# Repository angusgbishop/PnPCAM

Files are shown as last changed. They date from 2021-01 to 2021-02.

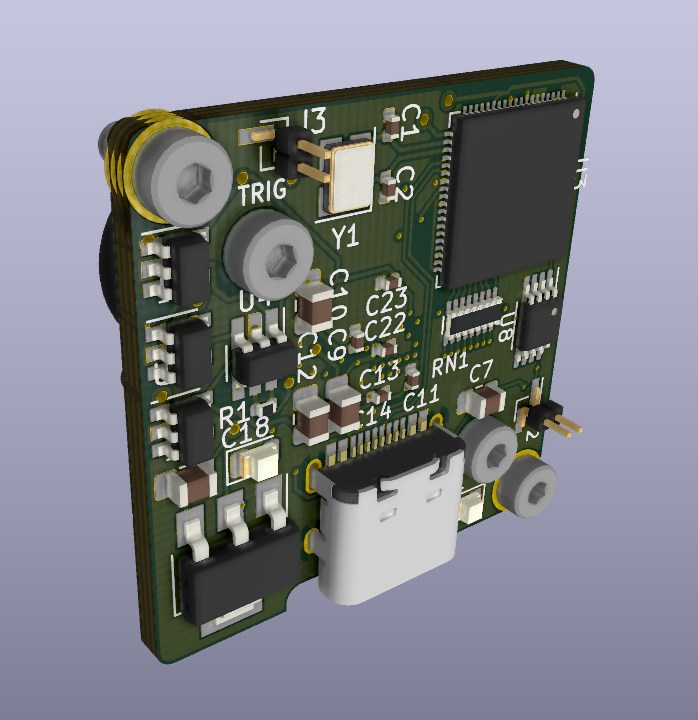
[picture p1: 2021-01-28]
OpenPnPVis Back.png

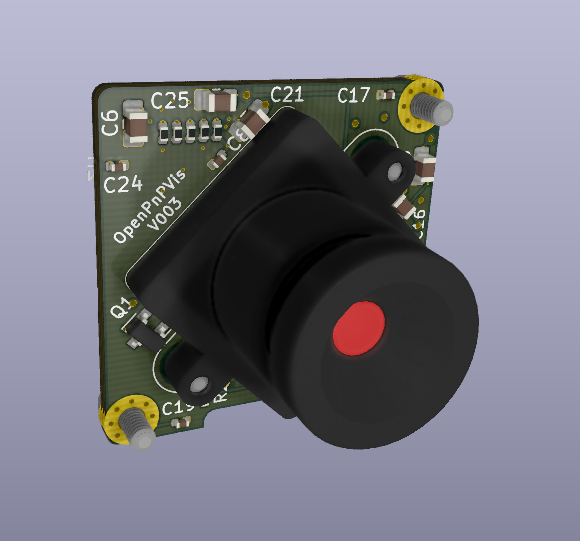
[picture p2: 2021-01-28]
OpenPnPVis Front.png

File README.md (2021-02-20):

# PnPCAM
 
PnPCAM is an [Open Hardware](https://www.oshwa.org/definition/) project dedicated to bringing high-quality machine vision to the various open source pick-and-place projects.

This project is very much **in development**, clone at your own risk!

The current versions of the board are based off the OnSemi AR0144 image sensor, as it is avaliable through mainline distributers at a reasonable cost for low quantities. 

* Up-to 1200x800 pixel resolution at 30fps (Currently limited by USB Bridge Chip)
* Global shutter
* Standard Webcam USB out
* <s>Onboard LED with exposure-triggered flash</s> (Requirement Dropped)
* LED Expansion Header for third-party use of the flash signal.
* Triggered shutter mode.
* Onboard lens distortion correction.

# Interested?
[View the Wiki here](https://github.com/angusgbishop/PnPCAM/wiki)

Find me on the [OpenPnP Discord](https://discord.gg/EmsrFVx)

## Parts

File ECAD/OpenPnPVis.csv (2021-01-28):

Reference | Quantity | Value | Footprint | Datasheet | MPN | SKU
C1 C2 | 2 | 16pF | Capacitor_SMD:C_0402_1005Metric | ~ | CC0402JRNPO9BN160
C10 C12 C14 C21 C25 C6 C3 C4 C15 C16 C18 C5 C7 | 13 | 10uF | Capacitor_SMD:C_0805_2012Metric_Pad1.15x1.40mm_HandSolder | ~ | CL21A106KOQNNNE
C9 C11 C13 C22 C23 C24 C8 C19 C17 | 9 | 100nF | Capacitor_SMD:C_0402_1005Metric | ~ | CC0402KRX7R7BB104
D1 D2 | 2 | LED | LED_SMD:LED_0805_2012Metric | ~ | ORH-B35A
H2 H1 | 2 | M3 | MountingHole:MountingHole_2.2mm_M2_Pad_Via | ~ | N/A
J2 J3 | 2 | Conn_01x02 | Connector_PinHeader_1.00mm:PinHeader_1x02_P1.00mm_Vertical_SMD_Pin1Left | ~
J4 | 1 | USB_C_Receptacle | Type-C:HRO-TYPE-C-31-M-12-Assembly | https://www.usb.org/sites/default/files/documents/usb_type-c.zip | TYPE-C-31-M-12
LENSMOUNT1 | 1 | CMT168-1122F | OpenPnPVis:CMT168-1122F | http://www.optics-online.com/Detail.asp?PN=CMT168-1122F | N/A
Q1 | 1 | SMD-MOSFET-P-CH-8V-4.1A-CJ2305_SOT-23_ | Package_TO_SOT_SMD:SOT-23 |  | CJ2305 | 305030014
R10 R11 R9 R12 R13 R8 | 6 | 1.6K | Resistor_SMD:R_0402_1005Metric | ~ | RC0402FR-071K5L
R19 R20 R4 R3 | 4 | 0R | Resistor_SMD:R_0402_1005Metric | ~ | RC0402FR-070RL
R2 | 1 | 85 | Resistor_SMD:R_0402_1005Metric | ~ | RC0402FR-0785RL
R5 R14 | 2 | 5.1K | Resistor_SMD:R_0402_1005Metric | ~ | RC0402FR-075K1L
R6 | 1 | 4.7K | Resistor_SMD:R_0402_1005Metric | ~ | RC0402FR-074K7L
R7 R1 | 2 | 10K | Resistor_SMD:R_0402_1005Metric | ~ | RC0402JR-0710KL
RN1 | 1 | 33 | Resistor_SMD:R_Array_Convex_8x0602 | ~ | EXB2HV330JV
U1 | 1 | AMS1117-3.3 | Package_TO_SOT_SMD:SOT-223-3_TabPin2 | http://www.advanced-monolithic.com/pdf/ds1117.pdf | AMS1117-3.3
U10 | 1 | AP2127K-2.5 | Package_TO_SOT_SMD:SOT-23-5 | https://www.diodes.com/assets/Datasheets/AP2127.pdf | AP2127K-2.5
U2 | 1 | AR0144 | OpenPnPVis:BGA-72_9x8_5.565x5.545mm |  | AR0144
U3 | 1 | FT602Q | Package_DFN_QFN:QFN-76-1EP_9x9mm_P0.4mm_EP3.8x3.8mm |  | FT602Q-B-T
U4 | 1 | ATtiny10-TS | Package_TO_SOT_SMD:SOT-23-6_Handsoldering | http://ww1.microchip.com/downloads/en/DeviceDoc/Atmel-8127-AVR-8-bit-Microcontroller-ATtiny4-ATtiny5-ATtiny9-ATtiny10_Datasheet.pdf | ATtiny10-TS
U6 | 1 | TPD2EUSB30 | Package_TO_SOT_SMD:Texas_DRT-3 | http://www.ti.com/lit/ds/symlink/tpd2eusb30a.pdf | TPD2EUSB30
U7 | 1 | AP2127K-2.8 | Package_TO_SOT_SMD:SOT-23-5 | https://www.diodes.com/assets/Datasheets/AP2127.pdf | AP2127K-2.8
U8 | 1 | 74LVC2G74 | Package_SO:MSOP-8_3x3mm_P0.65mm | http://www.ti.com/lit/sg/scyt129e/scyt129e.pdf | 74LVC2G74
U9 | 1 | AP2127K-1.2 | Package_TO_SOT_SMD:SOT-23-5 | https://www.diodes.com/assets/Datasheets/AP2127.pdf | AP2127K-1.2
Y1 | 1 | X3S030000BA1H-U | Crystal:Crystal_SMD_3225-4Pin_3.2x2.5mm | https://datasheet.lcsc.com/szlcsc/1912111437_HELE-Harmony-Elec-X3S030000BA1H-U_C254267.pdf | X3S030000BA1H-U

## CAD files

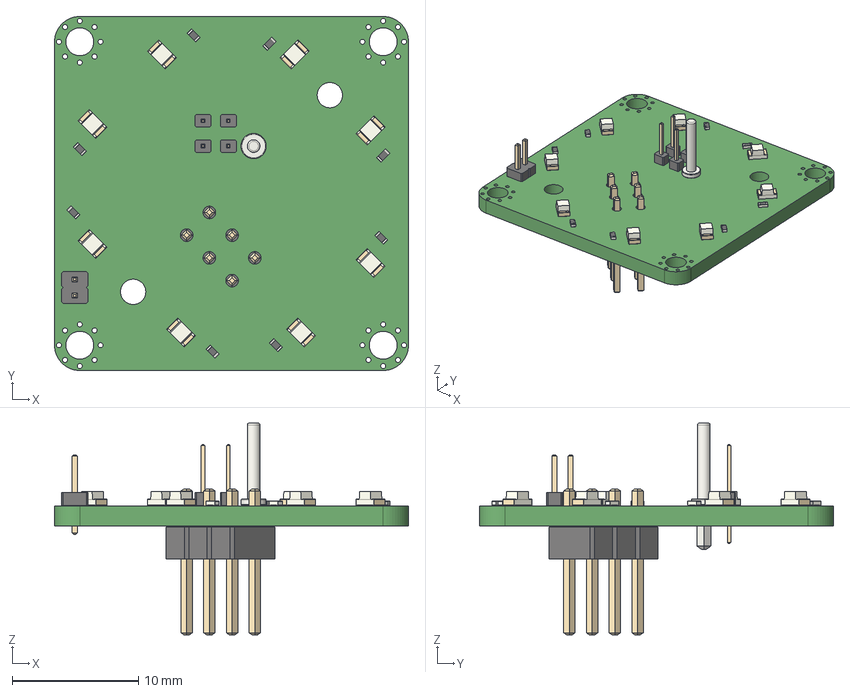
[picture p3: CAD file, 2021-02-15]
ECAD/Illumination Board/Illum/Illum.step
28.0 x 28.0 x 16.7 mm

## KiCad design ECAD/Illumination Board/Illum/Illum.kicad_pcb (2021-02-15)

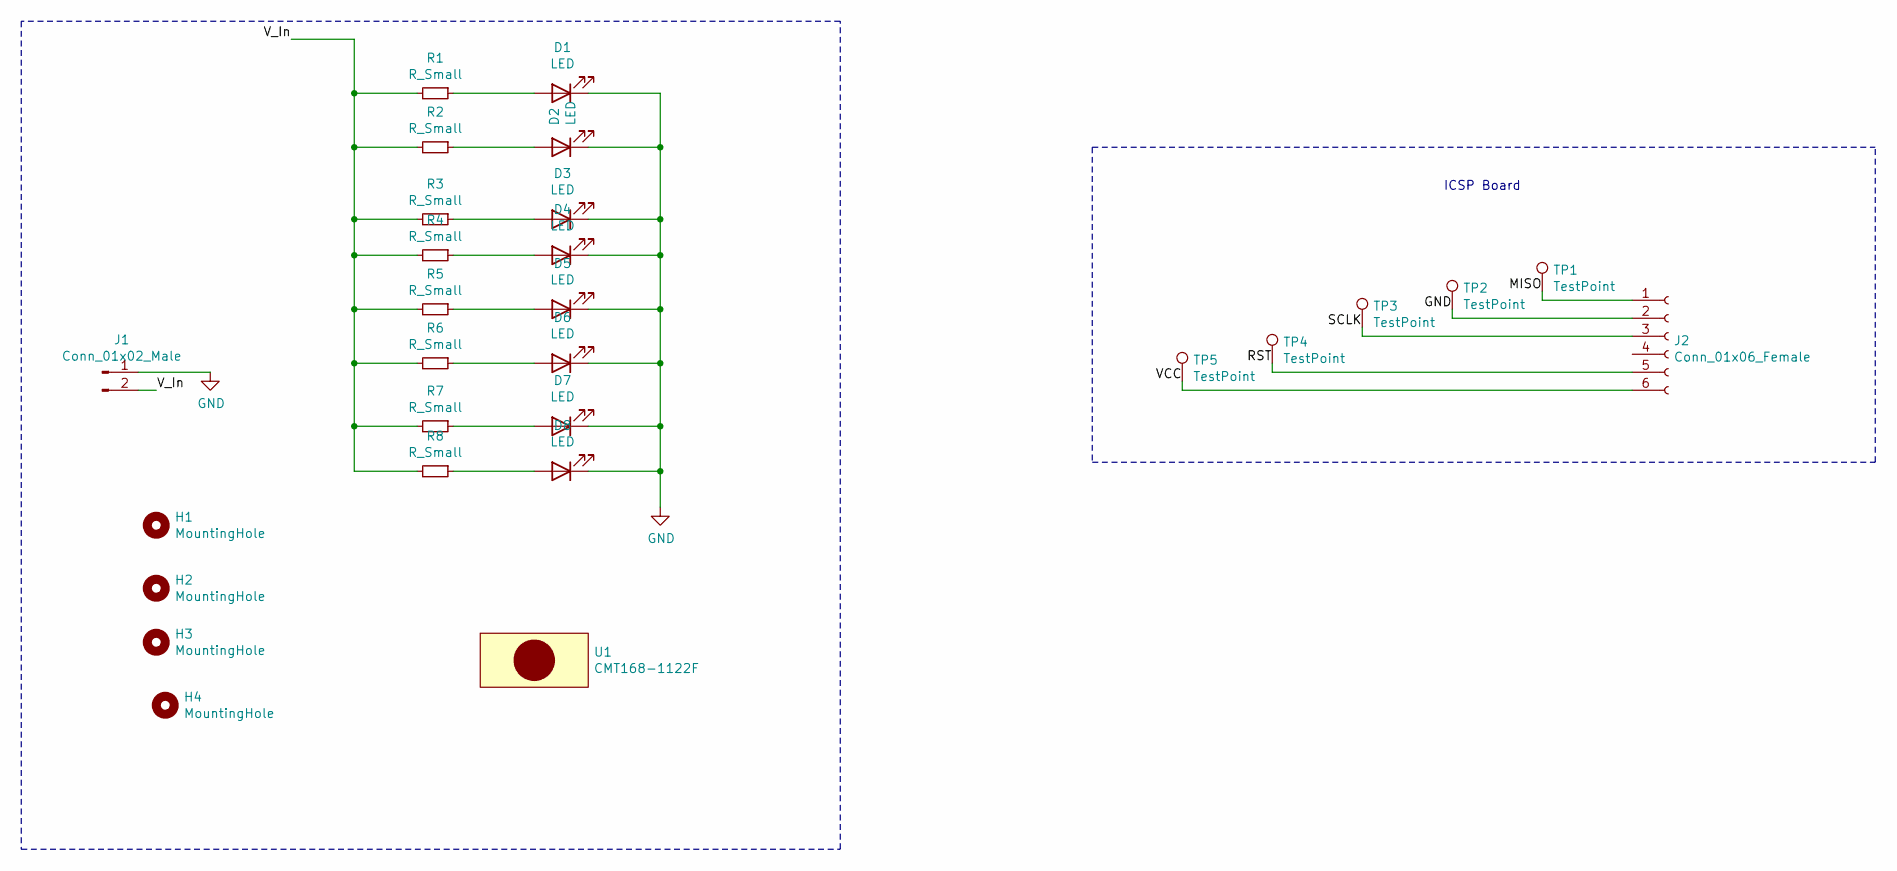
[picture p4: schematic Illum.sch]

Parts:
D1, D2, D3, D4, D5, D6, D7, D8: LED; LED_0805_2012Metric
H1, H2, H3, H4: MountingHole; MountingHole_2.2mm_M2_Pad_Via
J1: Conn_01x02_Male; PinHeader_1x02_P1.27mm_Vertical
J2: Conn_01x06_Female; PinHeader_2x03_P2.54mm_Vertical
R1, R2, R3, R4, R5, R6, R7, R8: R_Small; R_0402_1005Metric
TP1, TP2, TP3, TP4, TP5: TestPoint; PinHeader_1x01_P1.00mm_Vertical
U1: CMT168-1122F

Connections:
/MISO: J2.1, TP1.1
/RST: J2.5, TP4.1
/SCLK: J2.3, TP3.1
/VCC: J2.6, TP5.1
/V_In: J1.2, R1.2, R2.2, R3.2, R4.2, R5.2, R6.2, R7.2, R8.2
GND: D1.1 (K), D2.1 (K), D3.1 (K), D4.1 (K), D5.1 (K), D6.1 (K), D7.1 (K), D8.1 (K), J1.1, J2.2, TP2.1
unnamed: D1.2 (A), R1.1
unnamed: D2.2 (A), R2.1
unnamed: D3.2 (A), R3.1
unnamed: D4.2 (A), R4.1
unnamed: D5.2 (A), R5.1
unnamed: D6.2 (A), R6.1
unnamed: D7.2 (A), R7.1
unnamed: D8.2 (A), R8.1

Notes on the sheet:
ICSP Board

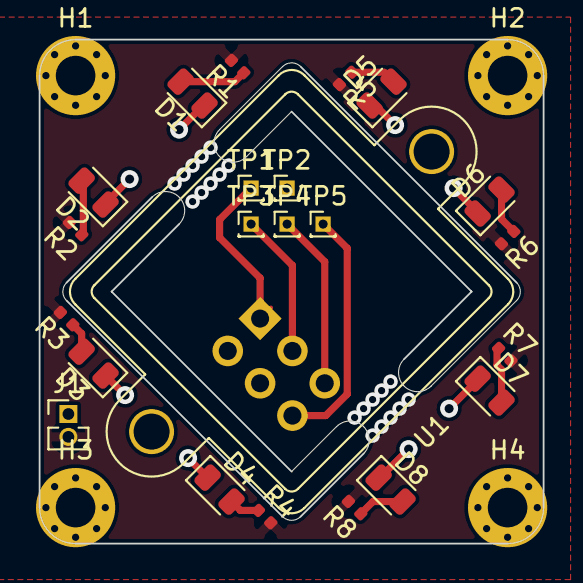
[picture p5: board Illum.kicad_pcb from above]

Board: 2 copper layers, 28.0 x 28.0 mm, 28 parts (1 on the bottom side), 14 nets.

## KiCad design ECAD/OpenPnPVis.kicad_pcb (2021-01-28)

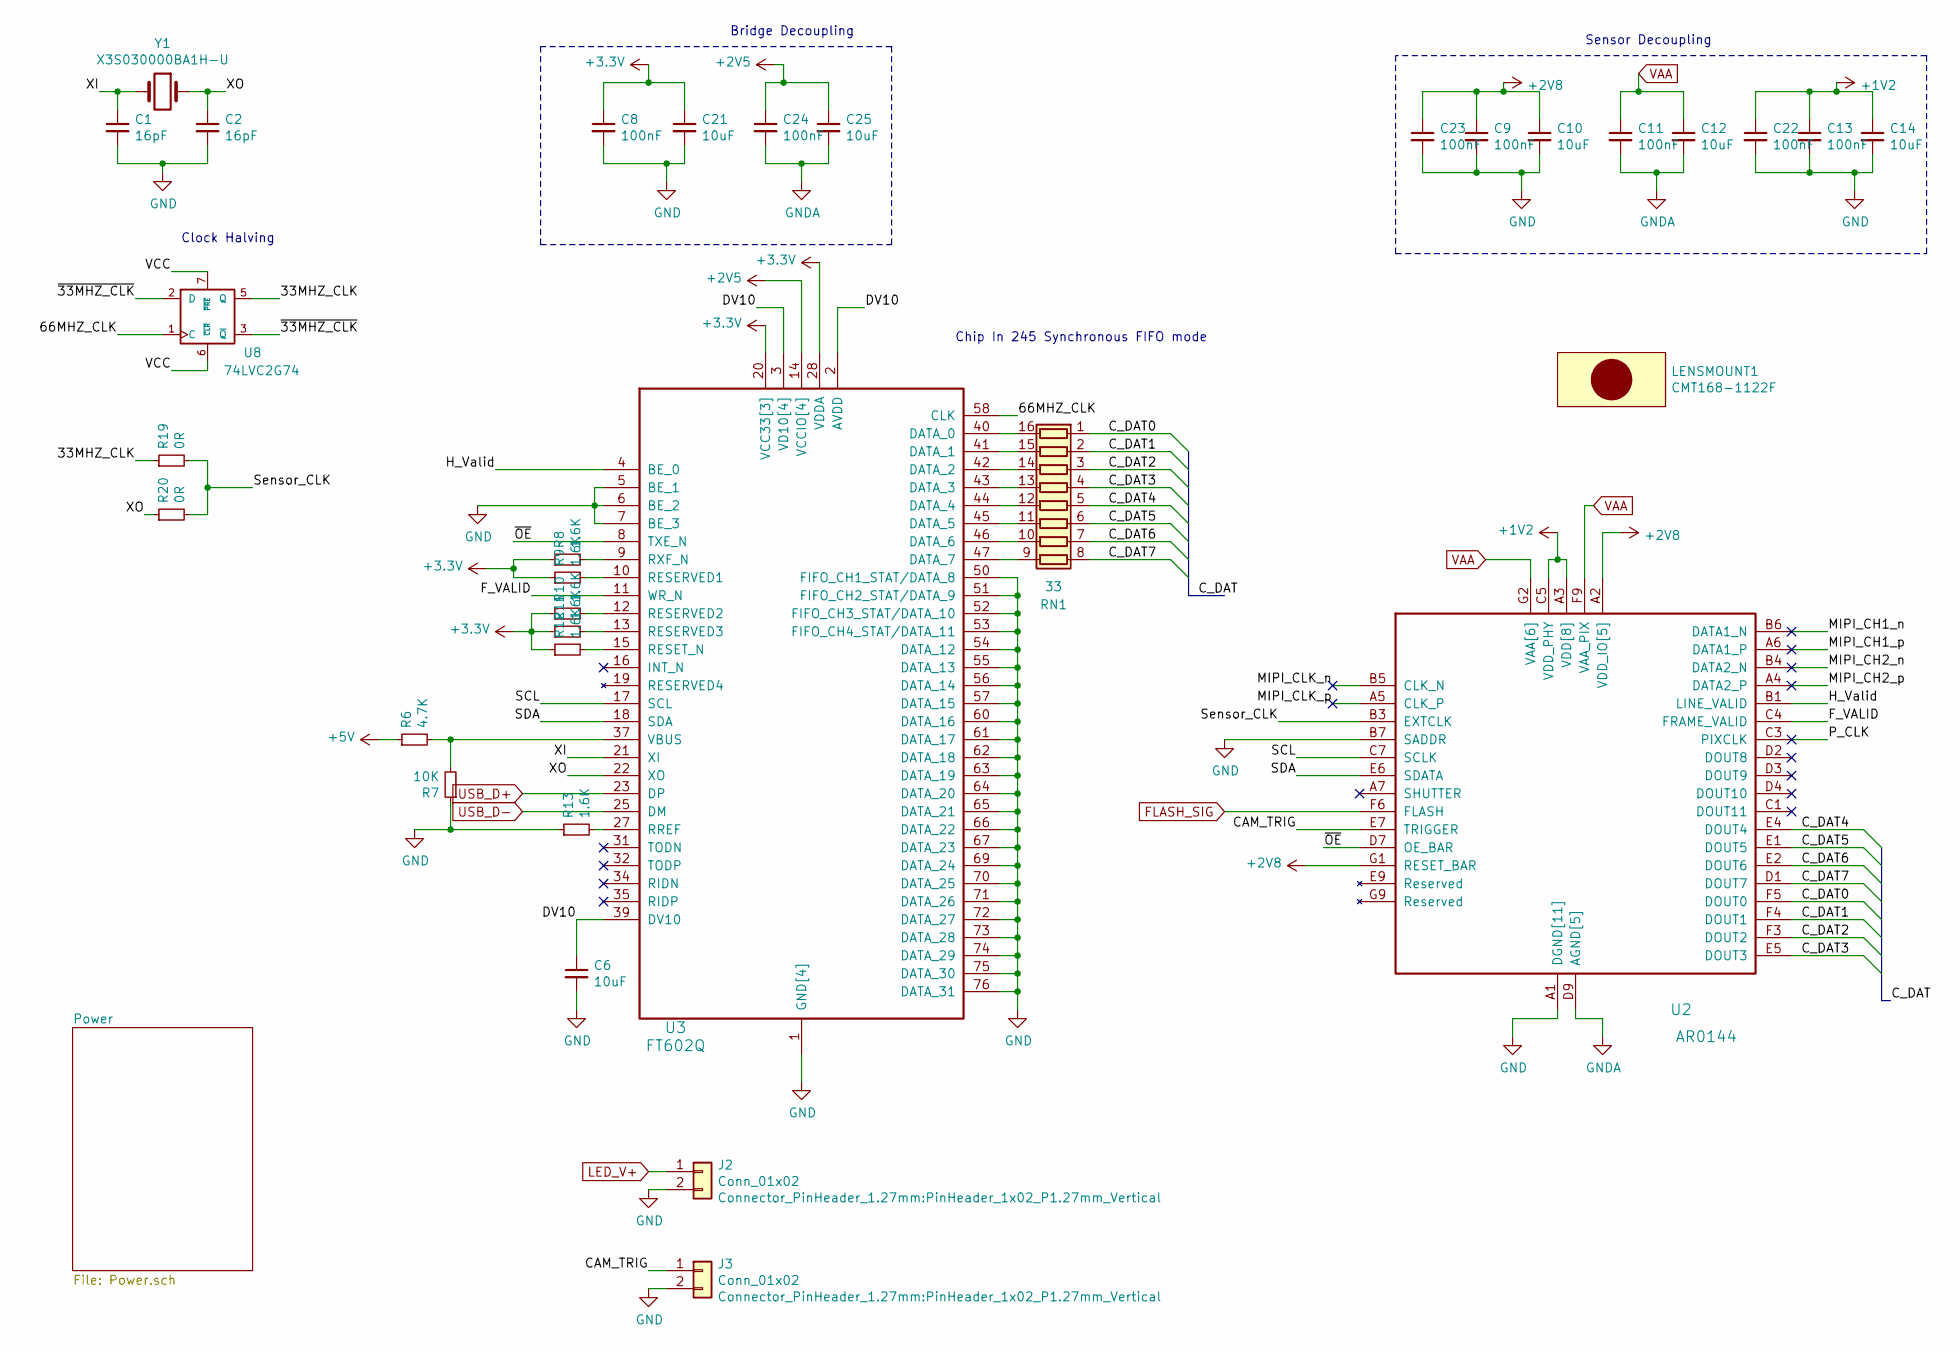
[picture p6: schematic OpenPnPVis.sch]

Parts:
C1, C2: 16pF; C_0402_1005Metric; MPN CC0402JRNPO9BN160
C6, C10, C12, C14, C21, C25: 10uF; C_0805_2012Metric_Pad1.15x1.40mm_HandSolder; MPN CL21A106KOQNNNE
C8, C9, C11, C13, C22, C23, C24: 100nF; C_0402_1005Metric; MPN CC0402KRX7R7BB104
J2, J3: Conn_01x02; PinHeader_1x02_P1.27mm_Vertical
LENSMOUNT1: CMT168-1122F; MPN N/A
R6: 4.7K; R_0402_1005Metric; MPN RC0402FR-074K7L
R7: 10K; R_0402_1005Metric; MPN RC0402JR-0710KL
R8, R9, R10, R11, R12, R13: 1.6K; R_0402_1005Metric; MPN RC0402FR-071K5L
R19, R20: 0R; R_0402_1005Metric; MPN RC0402FR-070RL
RN1: 33; R_Array_Convex_8x0602; MPN EXB2HV330JV
U2:  AR0144; BGA-72_9x8_5.565x5.545mm; MPN AR0144
U3: FT602Q; QFN-76-1EP_9x9mm_P0.4mm_EP3.8x3.8mm; MPN FT602Q-B-T
U8: 74LVC2G74; VSSOP-8_2.4x2.1mm_P0.5mm; MPN 74LVC2G74
Y1: X3S030000BA1H-U; Crystal_SMD_3225-4Pin_3.2x2.5mm; MPN X3S030000BA1H-U

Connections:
+1V2: C13.1, C14.1, C22.1, U2.A3 (VDD[8]), U2.B2 (VDD[8]), U2.C5 (VDD_PHY), U2.C6 (VDD[8]), U2.D8 (VDD[8]), U2.F2 (VDD[8]), U2.G4 (VDD[8]), U2.G5 (VDD[8]), U2.G6 (VDD[8]); also elsewhere on the board
+2V8: C9.1, C10.1, C23.1, U2.A2 (VDD_IO[5]), U2.B8 (VDD_IO[5]), U2.C2 (VDD_IO[5]), U2.C8 (VDD_IO[5]), U2.E3 (VDD_IO[5]), U2.G1 (RESET_BAR), U8.6 (~CLR), U8.7 (~PRE), U8.8 (VCC); also elsewhere on the board
+3V3: C8.1, C21.1, R8.1, R9.1, R10.1, R11.1, R12.1, U3.20 (VCC33[3]), U3.24 (VCC33[3]), U3.28 (VDDA), U3.38 (VCC33[3]); also elsewhere on the board
+5V: R6.1; also elsewhere on the board
/33MHZ_CLK: R19.1, U8.5 (Q)
/66MHZ_CLK: U3.58 (CLK), U8.1 (C)
/CAM_TRIG: J3.1, U2.E7 (TRIGGER)
/C_DAT0: RN1.1 (R1.1), U2.F5 (DOUT0)
/C_DAT1: RN1.2 (R2.1), U2.F4 (DOUT1)
/C_DAT2: RN1.3 (R3.1), U2.F3 (DOUT2)
/C_DAT3: RN1.4 (R4.1), U2.E5 (DOUT3)
/C_DAT4: RN1.5 (R5.1), U2.E4 (DOUT4)
/C_DAT5: RN1.6 (R6.1), U2.E1 (DOUT5)
/C_DAT6: RN1.7 (R7.1), U2.E2 (DOUT6)
/C_DAT7: RN1.8 (R8.1), U2.D1 (DOUT7)
/DV10: C6.1, U3.2 (AVDD), U3.3 (VD10[4]), U3.30 (VD10[4]), U3.33 (VD10[4]), U3.39 (DV10), U3.48 (VD10[4])
/F_VALID: U2.C4 (FRAME_VALID), U3.11 (WR_N)
/H_Valid: U2.B1 (LINE_VALID), U3.4 (BE_0)
/MIPI_CH1_n: U2.B6 (DATA1_N)
/MIPI_CH1_p: U2.A6 (DATA1_P)
/MIPI_CH2_n: U2.B4 (DATA2_N)
/MIPI_CH2_p: U2.A4 (DATA2_P)
/MIPI_CLK_n: U2.B5 (CLK_N)
/MIPI_CLK_p: U2.A5 (CLK_P)
/P_CLK: U2.C3 (PIXCLK)
/SCL: U2.C7 (SCLK), U3.17 (SCL)
/SDA: U2.E6 (SDATA), U3.18 (SDA)
/Sensor_CLK: R19.2, R20.2, U2.B3 (EXTCLK)
/XI: C1.1, U3.21 (XI), Y1.2
/XO: C2.1, R20.1, U3.22 (XO), Y1.1
/~33MHZ_CLK: U8.2 (D), U8.3 (~Q)
/~OE: U2.D7 (OE_BAR), U3.8 (TXE_N)
FLASH_SIG: U2.F6 (FLASH); also elsewhere on the board
GND: C1.2, C2.2, C6.2, C8.2, C9.2, C10.2, C11.2, C12.2, C13.2, C14.2, C21.2, C22.2, C23.2, C24.2, C25.2, J2.2, J3.2, R7.1, R13.1, U2.A1 (DGND[11]), U2.A8 (DGND[11]), U2.B7 (SADDR), U2.D5 (DGND[11]), U2.D6 (DGND[11]), U2.D9 (AGND[5]), U2.E8 (DGND[11]), U2.F1 (DGND[11]), U2.F7 (DGND[11]), U2.F8 (DGND[11]), U2.G3 (AGND[5]), U2.G7 (AGND[5]), U2.H3 (AGND[5]), U2.H4 (DGND[11]), U2.H5 (DGND[11]), U2.H6 (DGND[11]), U2.H7 (AGND[5]), U3.1 (GND[4]), U3.5 (BE_1), U3.6 (BE_2), U3.7 (BE_3), U3.26 (GND[4]), U3.29 (GND[4]), U3.36 (GND[4]), U3.50 (FIFO_CH1_STAT/DATA_8), U3.51 (FIFO_CH2_STAT/DATA_9), U3.52 (FIFO_CH3_STAT/DATA_10), U3.53 (FIFO_CH4_STAT/DATA_11), U3.54 (DATA_12), U3.55 (DATA_13), U3.56 (DATA_14), U3.57 (DATA_15), U3.60 (DATA_16), U3.61 (DATA_17), U3.62 (DATA_18), U3.63 (DATA_19), U3.64 (DATA_20), U3.65 (DATA_21), U3.66 (DATA_22), U3.67 (DATA_23), U3.69 (DATA_24), U3.70 (DATA_25), U3.71 (DATA_26), U3.72 (DATA_27), U3.73 (DATA_28), U3.74 (DATA_29), U3.75 (DATA_30), U3.76 (DATA_31), U3.77 (GND[4]), U8.4 (GND); also elsewhere on the board
LED_V+: J2.1; also elsewhere on the board
unnamed: R6.2, R7.2, U3.37 (VBUS)
unnamed: R8.2, U3.9 (RXF_N)
unnamed: R9.2, U3.10 (RESERVED1)
unnamed: R10.2, U3.12 (RESERVED2)
unnamed: R11.2, U3.13 (RESERVED3)
unnamed: R12.2, U3.15 (RESET_N)
unnamed: R13.2, U3.27 (RREF)
unnamed: RN1.9 (R8.2), U3.47 (DATA_7)
unnamed: RN1.10 (R7.2), U3.46 (DATA_6)
unnamed: RN1.11 (R6.2), U3.45 (DATA_5)
unnamed: RN1.12 (R5.2), U3.44 (DATA_4)
unnamed: RN1.13 (R4.2), U3.43 (DATA_3)
unnamed: RN1.14 (R3.2), U3.42 (DATA_2)
unnamed: RN1.15 (R2.2), U3.41 (DATA_1)
unnamed: RN1.16 (R1.2), U3.40 (DATA_0)
USB_D+: U3.23 (DP); also elsewhere on the board
USB_D-: U3.25 (DM); also elsewhere on the board
VAA: C11.1, C12.1, C24.1, C25.1, U2.F9 (VAA_PIX), U2.G2 (VAA[6]), U2.G8 (VAA[6]), U2.H1 (VAA[6]), U2.H2 (VAA[6]), U2.H8 (VAA[6]), U2.H9 (VAA[6]), U3.14 (VCCIO[4]), U3.49 (VCCIO[4]), U3.59 (VCCIO[4]), U3.68 (VCCIO[4]); also elsewhere on the board

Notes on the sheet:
Sensor Decoupling
Clock Halving
Chip In 245 Synchronous FIFO mode
Bridge Decoupling

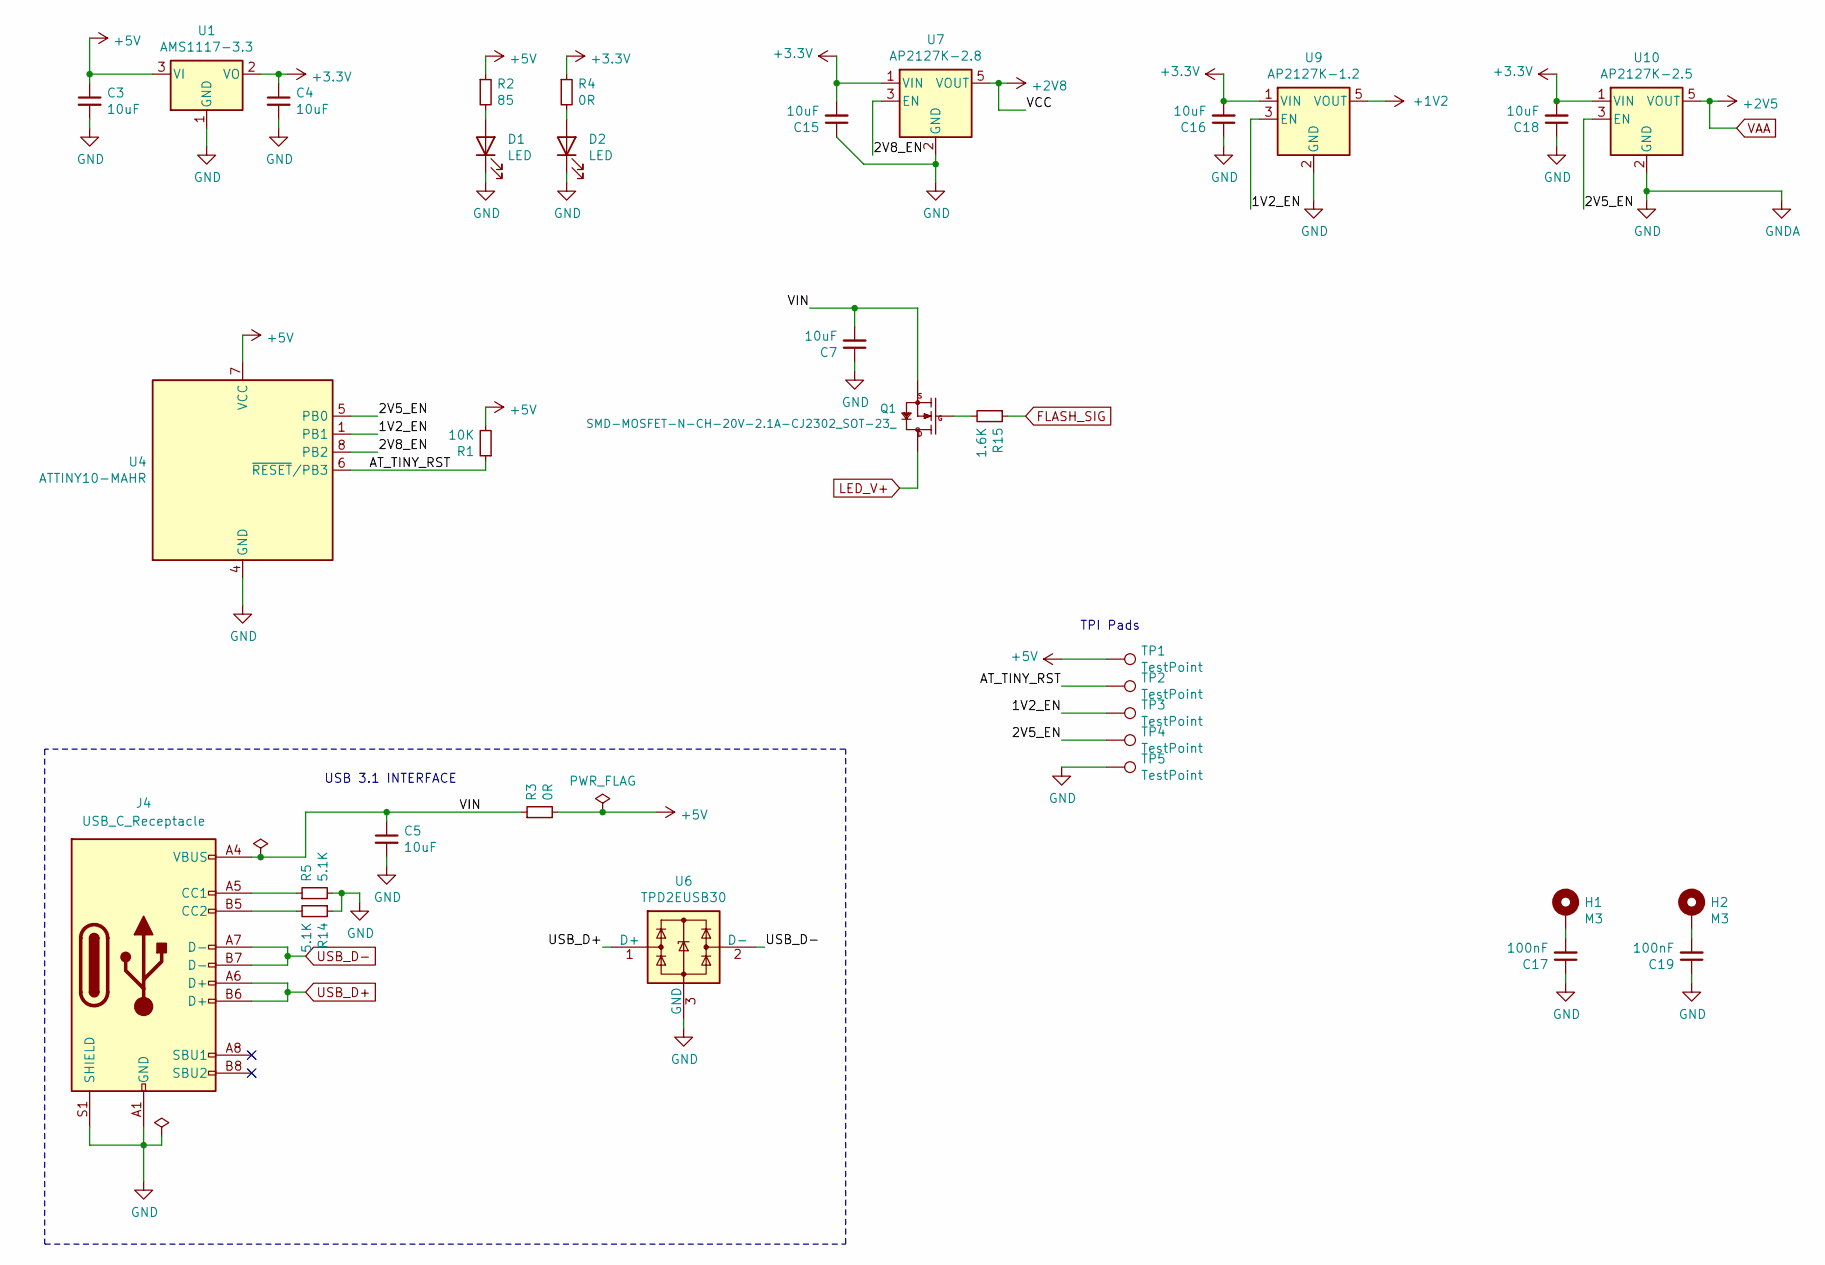
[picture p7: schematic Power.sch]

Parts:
C3, C4, C5, C7, C15, C16, C18: 10uF; C_0805_2012Metric_Pad1.15x1.40mm_HandSolder; MPN CL21A106KOQNNNE
C17, C19: 100nF; C_0402_1005Metric; MPN CC0402KRX7R7BB104
D1, D2: LED; LED_0805_2012Metric; MPN ORH-B35A
H1, H2: M3; MountingHole_2.2mm_M2_Pad_Via; MPN N/A
J4: USB_C_Receptacle; HRO-TYPE-C-31-M-12-Assembly; MPN TYPE-C-31-M-12
Q1: SMD-MOSFET-N-CH-20V-2.1A-CJ2302_SOT-23_; SOT-23; MPN CJ2302
R1: 10K; R_0402_1005Metric; MPN RC0402JR-0710KL
R2: 85; R_0402_1005Metric; MPN RC0402FR-0785RL
R3, R4: 0R; R_0402_1005Metric; MPN RC0402FR-070RL
R5, R14: 5.1K; R_0402_1005Metric; MPN RC0402FR-075K1L
R15: 1.6K; R_0402_1005Metric; MPN RC0402FR-070RL
TP1, TP2, TP3, TP4, TP5: TestPoint; TestPoint_Pad_1.0x1.0mm
U1: AMS1117-3.3; SOT-223-3_TabPin2; MPN AMS1117-3.3
U4: ATTINY10-MAHR; DFN-8-1EP_2x2mm_P0.5mm_EP0.9x1.5mm; MPN ATTINY10-MAHR
U6: TPD2EUSB30; Texas_DRT-3; MPN TPD2EUSB30
U7: AP2127K-2.8; SOT-23-5; MPN AP2127K-2.8
U9: AP2127K-1.2; SOT-23-5; MPN AP2127K-1.2
U10: AP2127K-2.5; SOT-23-5; MPN AP2127K-2.5

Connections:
+1V2: U9.5 (VOUT); also elsewhere on the board
+2V8: U7.5 (VOUT); also elsewhere on the board
+3V3: C4.1, C15.2, C16.2, C18.2, R4.1, U1.2 (VO), U7.1 (VIN), U9.1 (VIN), U10.1 (VIN); also elsewhere on the board
+5V: C3.1, R1.2, R2.1, R3.2, TP1.1, U1.3 (VI), U4.7 (VCC); also elsewhere on the board
/Power/1V2_EN: TP3.1, U4.1 (PB1), U9.3 (EN)
/Power/2V5_EN: TP4.1, U4.5 (PB0), U10.3 (EN)
/Power/2V8_EN: U4.8 (PB2), U7.3 (EN)
/Power/AT_TINY_RST: R1.1, TP2.1, U4.6 (~RESET~/PB3)
/Power/VIN: C5.1, C7.2, J4.A4 (VBUS), J4.A9 (VBUS), J4.B4 (VBUS), J4.B9 (VBUS), Q1.2 (S), R3.1
FLASH_SIG: R15.1; also elsewhere on the board
GND: C3.2, C4.2, C5.2, C7.1, C15.1, C16.1, C17.1, C18.1, C19.1, D1.1 (K), D2.1 (K), J4.A1 (GND), J4.A12 (GND), J4.B1 (GND), J4.B12 (GND), J4.S1 (SHIELD), R5.2, R14.1, TP5.1, U1.1 (GND), U4.4 (GND), U6.3 (GND), U7.2 (GND), U9.2 (GND), U10.2 (GND); also elsewhere on the board
LED_V+: Q1.3 (D); also elsewhere on the board
unnamed: C17.2, H1.1
unnamed: C19.2, H2.1
unnamed: D1.2 (A), R2.2
unnamed: D2.2 (A), R4.2
unnamed: J4.A5 (CC1), R5.1
unnamed: J4.B5 (CC2), R14.2
unnamed: Q1.1 (G), R15.2
USB_D+: J4.A6 (D+), J4.B6 (D+), U6.1 (D+); also elsewhere on the board
USB_D-: J4.A7 (D-), J4.B7 (D-), U6.2 (D-); also elsewhere on the board
VAA: U10.5 (VOUT); also elsewhere on the board

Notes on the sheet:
USB 3.1 INTERFACE
TPI Pads

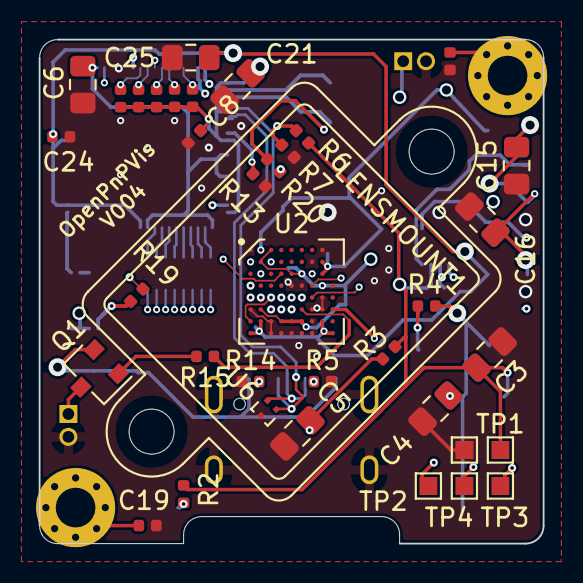
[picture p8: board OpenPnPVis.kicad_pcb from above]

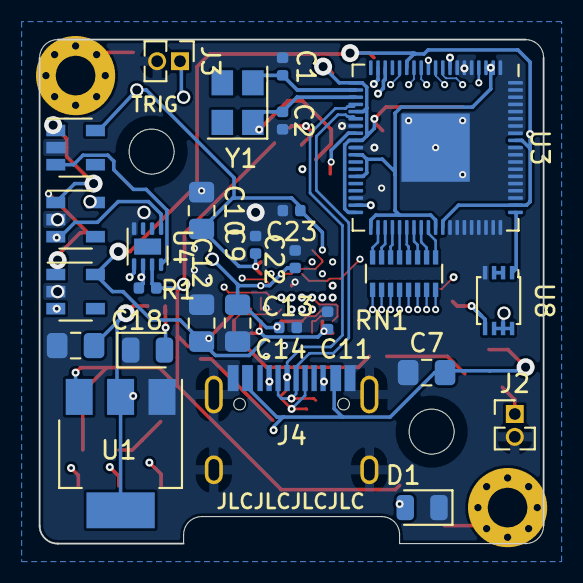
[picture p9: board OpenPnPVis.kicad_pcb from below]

Board: 4 copper layers, 28.0 x 28.0 mm, 66 parts (27 on the bottom side), 58 nets.

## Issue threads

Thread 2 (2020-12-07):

Are on-board LED's effective?

angusgbishop, 2020-12-07:
Current revision has a pentagon pattern of LED's.

These are in a small package and may not be bright enough for the illumination required. How much additional board space is required for adequate illumination?

Due to the short operating time, these may be able to be driven very hard to make up for dimness.

Two are most likely casting shadows behind the USB connector.

Is ideal placement of LED's on an angle?

Closed 2021-01-25.

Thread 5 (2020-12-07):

Image Sensor / USB Chip Interface

angusgbishop, 2020-12-07:
The USB Bridge chip is (most likely) expected to be integrated with an FPGA, and drives a data clock for the parallel data bus.

The Image sensor sets up its own data clock labels "PIXCLK" This can be driven at many frequencies depending on register settings in the image sensor.

The current implementation halves the data clock (66MHz) coming out from the Bridge chip (to 33MHz) and uses this as the input clock for the image sensor. This clock signal is then pushed through the Image sensor's PLL to produce a data bus at 66MHz. The sensor's Pixel Clock is left unconnected.

Alternative suggestions;

- Use the USB's Crystal oscillator signal as the driving source for the Image sensor.
This eliminates propagation delay through the flip-flop, but propagation delay through the USB chip itself is an unknown. Selectable resistors (R19 & R20) have been implemented in V002 to validate both options.

- Add a FIFO to the Bus, clock data in with the Image sensor PIXCLK and out with the bridge chip's data clock.
This takes up board space, increases BOM cost and complexity of the design.
I haven't really looked at this as an option so far.

- Use the CYUSB3064 from Cypress and switch to MIPI output.
"Plug and Play" IC that's freely available (OV580 isn't in distributors)
Adds another BGA to the BOM, and the IC is twice the price of the FT602Q-B at volume.

I'm open to any and all suggestions as well.

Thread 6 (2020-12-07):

Placeholder Values of Components

angusgbishop, 2020-12-07:
The following Components are current placeholders;

- R1-R5 - LED Resistors
- D1-D5 - Main illumination LED's
- C1, C2 - Crystal capacitors

- R17,R18 Board Power Indicator Resistors

Closed 2021-01-25.

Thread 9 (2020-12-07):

Mechanical Mounting

angusgbishop, 2020-12-07:
Current Mounting is designed for the Index Pick and Place's PEEK array of mounting holes. (M3 at 30x30mm)

However, the current revision of the board will likely fit inside a NEMA17 enclosure. Add additional drill holes at 31mmx31mm spacing to make it NEMA 17 compatible.

angusgbishop, 2020-12-14:
Improvements can be made to reduce PCB size.

Current Target is 28mm x 28mm.
It may still be possible to use the Peek array on the Index by rotating the board by 45deg. I'll need to do some investigation.

I will re-lay the circuit board and change the USB 3.1 Type B receptacle to a USB Type C to save most of the space. This will also help with the shadows caused by the current receptacle.

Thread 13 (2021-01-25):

Current through D1 too high

angusgbishop, 2021-01-25:
In testing the 602Q will not power up if the R2 resistor is fitted.

Tested setups below

R2 = NF - Working
R2 = 0Ohm - Not working, LED hot
R2 = 86.6Ohm - A USB device appears to windows but is non functional.

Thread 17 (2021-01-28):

Migrate Power sequencing IC to ATTiny1606

angusgbishop, 2021-01-28:
Current ATTiny10 is fine for power sequencing, however In current implementation it does not do detection of a de-powering event.

The Image sensor requires strict power up and power down control without this, the sensor may be damaged.

Suggest moving towards an ATTiny1606 for the Brown-out detection, increased flash and increased I/O.

angusgbishop, 2021-02-17:
Done in Rev005

Closed 2021-02-17.

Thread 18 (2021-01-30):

Clock input needs to be controlled as part of AR0144 power up sequence

angusgbishop, 2021-01-30:

angusgbishop, 2021-02-17:
Flip flop set pin now tied to ATtiny, requires testing to validate that this disables the 33Mhz Clock

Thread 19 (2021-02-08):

Logic Level of Power LDO's should be 3V3.

angusgbishop, 2021-02-08:
Power enable inputs on the 2V8 and 1V2 LDO's are constrained to VCC+/-0.3V.

Texas Instruments has a pin compatible part (TPS7A20) that has a more tolerant input. Alternativley the ATtiny10 could be run from 3V3 (and programmed off-board)

angusgbishop, 2021-02-17:
Migrated to TPS7A20 from Rev004, testing required to validate correct behaviour.

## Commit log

2020-12-06 First Commit
    Commit of V002
    [ImageSensor.sch, Micro.sch, OpenPnPVis.kicad_pcb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]
2020-12-13 Added Courtyard to Lens mount
    [OpenPnPVis.kicad_pcb, OpenPnPVis.sch]
2020-12-14 Tidied Schematic and added more to readme
    [OpenPnPVis.sch, Power.sch]
2020-12-14 Updated Crystal and LED Resistors
    Updated Crystal Capacitors to 16pF and 5V series resistors for LED's to 85Ohm.
    [OpenPnPVis.sch, Power.sch]
2020-12-17 Library Updates
    Added stp files for the lens mount, mounting screws, and image sensor.
2020-12-17 Creation of Rev003
    Creation of Rev003. This is a mini-sized board for easier fitment into tight spaces. The USB connector has changed to a USB Type-C. Some components have changed footprint to 0402.
    [OpenPnPVis.kicad_pcb, OpenPnPVis.sch, Power.sch]
2021-01-28 V004 Update
    Added ICSP pads
    Updated 74LVC2G74 footprint
    [OpenPnPVis-B_Cu.gbr, OpenPnPVis-B_Mask.gbr, OpenPnPVis-B_Paste.gbr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]
2021-01-28 V001 Illumination Board
    Creation of Illumination board and Programming board for Camera.
    [Illum-B_Cu.gbr, Illum-B_Mask.gbr, Illum-B_Paste.gbr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]
2021-02-12 Library Tweaks
    Twaks to libraries
    Illumination board updates
    [Illum.kicad_pcb]
2021-02-15 V005 Release
    V0005 Replaces the ATTINY10 with an ATTINY1606, It also adds a breakaway expansion I/O and programming header.
    The ATTINY is now on the I2C bus, and the flip/flop reset is now tied to the ATTINY GPIO.
    [OpenPnPVis.sch, Power.sch]
